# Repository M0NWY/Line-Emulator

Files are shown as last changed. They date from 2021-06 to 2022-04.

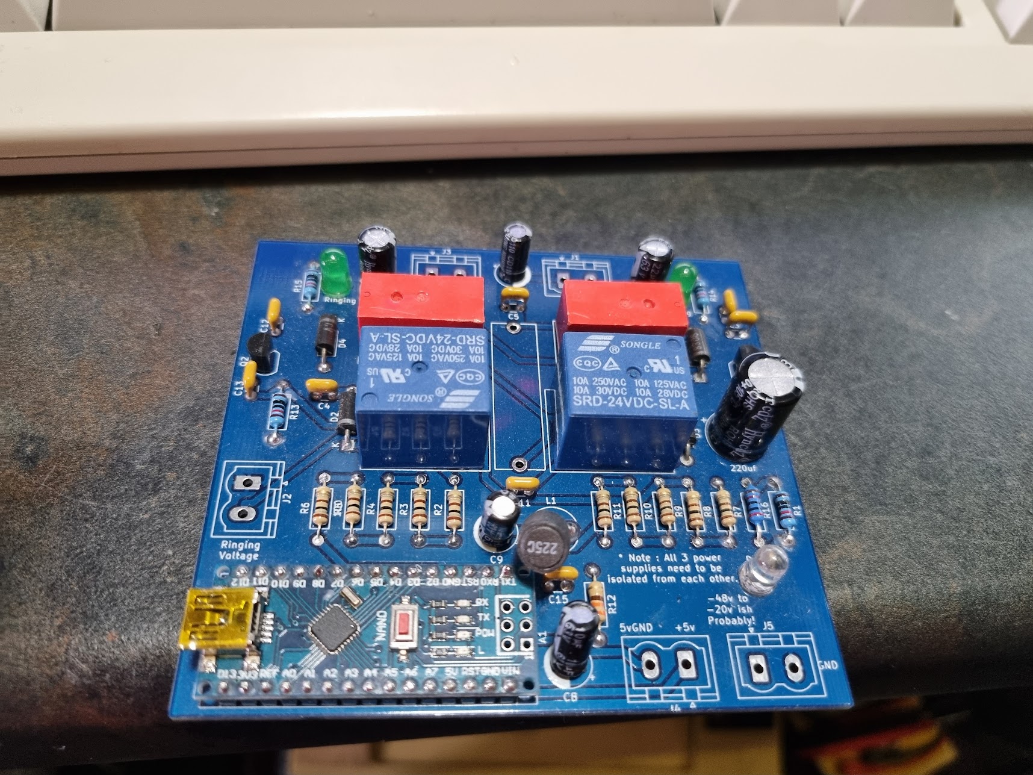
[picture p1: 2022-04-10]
lineemufront.jpg

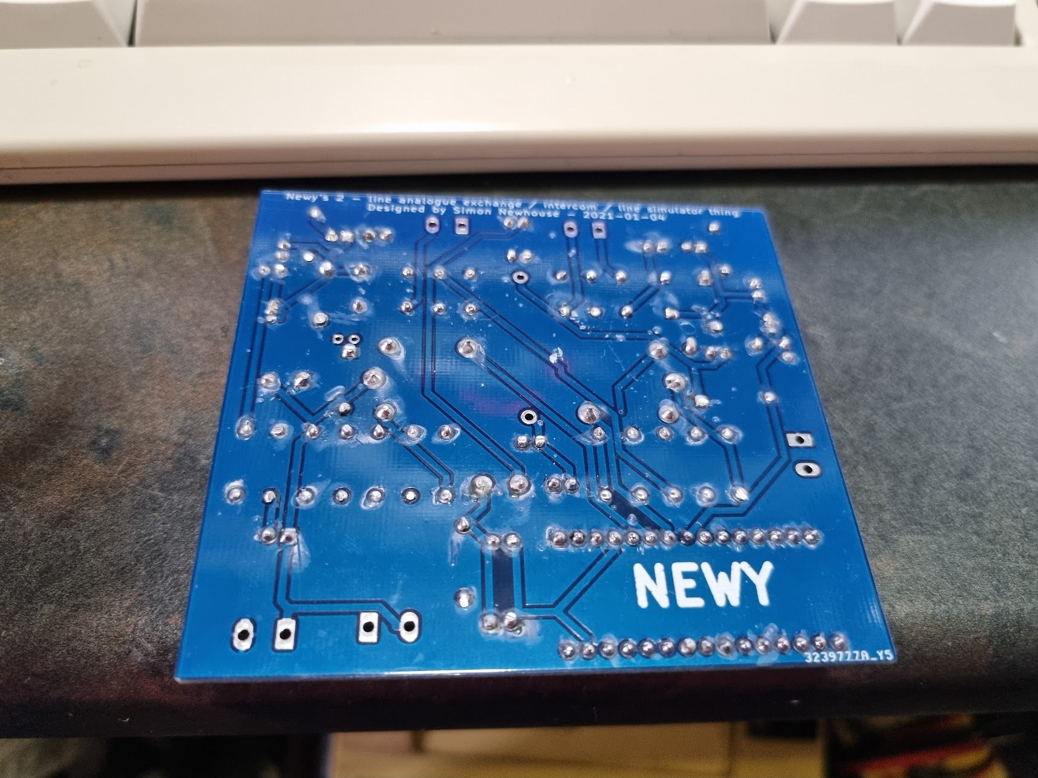
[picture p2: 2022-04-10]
lineemuback.jpg

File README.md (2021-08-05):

# Line-Emulator
I wanted a thing that would let me connect two modems together, so I could connect my dreamcast to the internet. 
In 2020.
This is the result. It is also a dedicated hotline / intercom thing. Will work with most old analogue phones.
Includes an emulated dial tone with a delay before ringing the other line, standard uk ringing cadence and a timeout if the other line does not answer.

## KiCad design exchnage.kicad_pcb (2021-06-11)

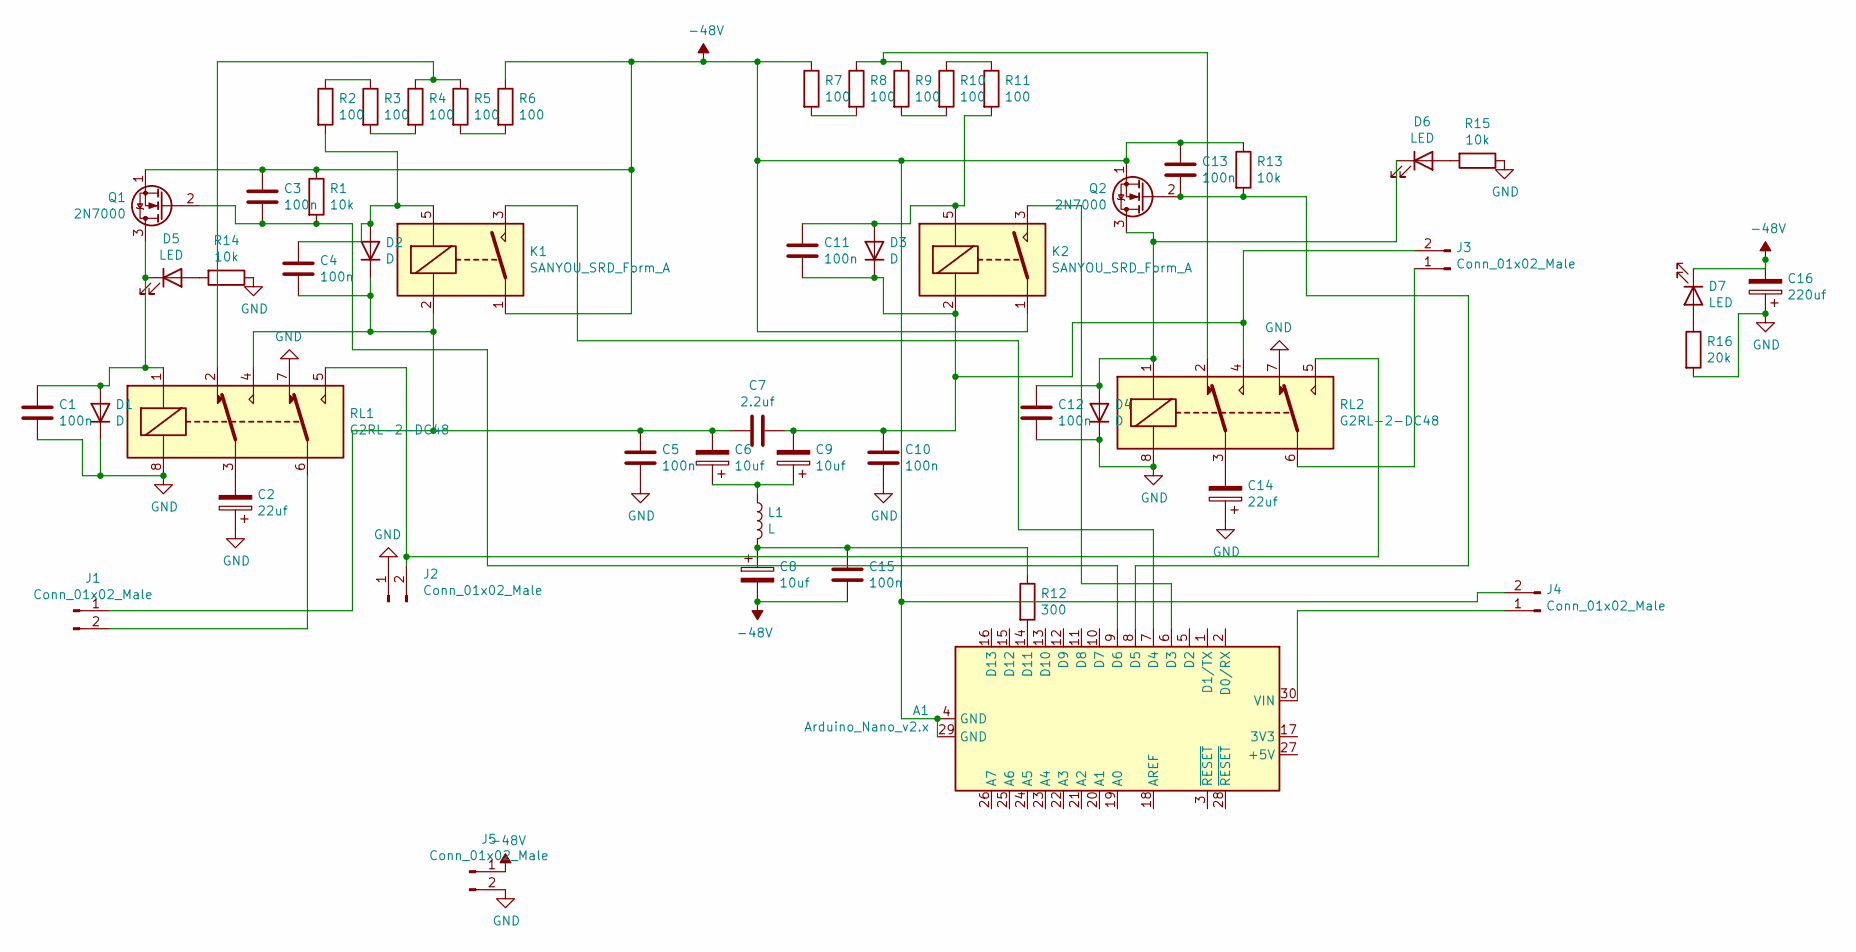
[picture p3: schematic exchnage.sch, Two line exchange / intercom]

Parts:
A1: Arduino_Nano_v2.x; Arduino_Nano
C1, C3, C4, C5, C10, C11, C12, C13, C15: 100n; C_Disc_D3.0mm_W1.6mm_P2.50mm
C2, C14: 22uf; CP_Radial_D6.3mm_P2.50mm
C6, C8, C9: 10uf; CP_Radial_D6.3mm_P2.50mm
C7: 2.2uf; C_Rect_L29.0mm_W7.6mm_P27.50mm_MKT
C16: 220uf; CP_Radial_D10.0mm_P5.00mm
D1, D2, D3, D4: D; D_A-405_P10.16mm_Horizontal
D5, D6, D7: LED; LED_D3.0mm
J1, J2, J3, J4, J5: Conn_01x02_Male; PhoenixContact_MSTBVA_2,5_2-G-5,08_1x02_P5.08mm_Vertical
K1, K2: SANYOU_SRD_Form_A; Relay_SPST_SANYOU_SRD_Series_Form_A
L1: L; L_Radial_D7.5mm_P5.00mm_Fastron_07P
Q1, Q2: 2N7000; TO-92_Inline
R1, R13, R14, R15: 10k; R_Axial_DIN0207_L6.3mm_D2.5mm_P10.16mm_Horizontal
R2, R3, R4, R5, R6, R7, R8, R9, R10, R11: 100; R_Axial_DIN0207_L6.3mm_D2.5mm_P10.16mm_Horizontal
R12: 300; R_Axial_DIN0207_L6.3mm_D2.5mm_P10.16mm_Horizontal
R16: 20k; R_Axial_DIN0207_L6.3mm_D2.5mm_P10.16mm_Horizontal
RL1, RL2: G2RL-2-DC48; Relay_DPDT_Omron_G2RL

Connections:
-48V: A1.4 (GND), A1.29 (GND), C3.1, C8.2, C13.1, C15.2, C16.2, D7.1 (K), J4.2, J5.1, K1.1, K2.1, Q1.1 (S), Q2.1 (S), R1.1, R6.1, R7.1, R13.1
GND: C1.2, C2.1, C5.2, C10.2, C12.2, C14.1, C16.1, D1.1 (K), D4.1 (K), J2.1, J5.2, R14.1, R15.1, R16.2, RL1.7, RL1.8, RL2.7, RL2.8
unnamed: A1.6 (D3), K2.3
unnamed: A1.7 (D4), K1.3
unnamed: A1.8 (D5), C13.2, Q2.2 (G), R13.2
unnamed: A1.9 (D6), C3.2, Q1.2 (G), R1.2
unnamed: A1.14 (D11), R12.2
unnamed: A1.30 (VIN), J4.1
unnamed: C1.1, D1.2 (A), D5.1 (K), Q1.3 (D), RL1.1
unnamed: C2.2, RL1.3
unnamed: C4.1, D2.2 (A), K1.5, R2.2
unnamed: C4.2, C5.1, C6.2, C7.2, D2.1 (K), J1.1, K1.2, RL1.4
unnamed: C6.1, C9.1, L1.1
unnamed: C7.1, C9.2, C10.1, C11.2, D3.1 (K), J3.2, K2.2, RL2.4
unnamed: C11.1, D3.2 (A), K2.5, R11.2
unnamed: C12.1, D4.2 (A), D6.1 (K), Q2.3 (D), RL2.1
unnamed: C14.2, RL2.3
unnamed: C8.1, C15.1, L1.2, R12.1
unnamed: D5.2 (A), R14.2
unnamed: D6.2 (A), R15.2
unnamed: D7.2 (A), R16.1
unnamed: J1.2, RL1.6
unnamed: J2.2, RL1.5, RL2.5
unnamed: J3.1, RL2.6
unnamed: R2.1, R3.1
unnamed: R3.2, R4.2
unnamed: R4.1, R5.1, RL1.2
unnamed: R5.2, R6.2
unnamed: R7.2, R8.2
unnamed: R8.1, R9.1, RL2.2
unnamed: R10.1, R11.1
unnamed: R9.2, R10.2

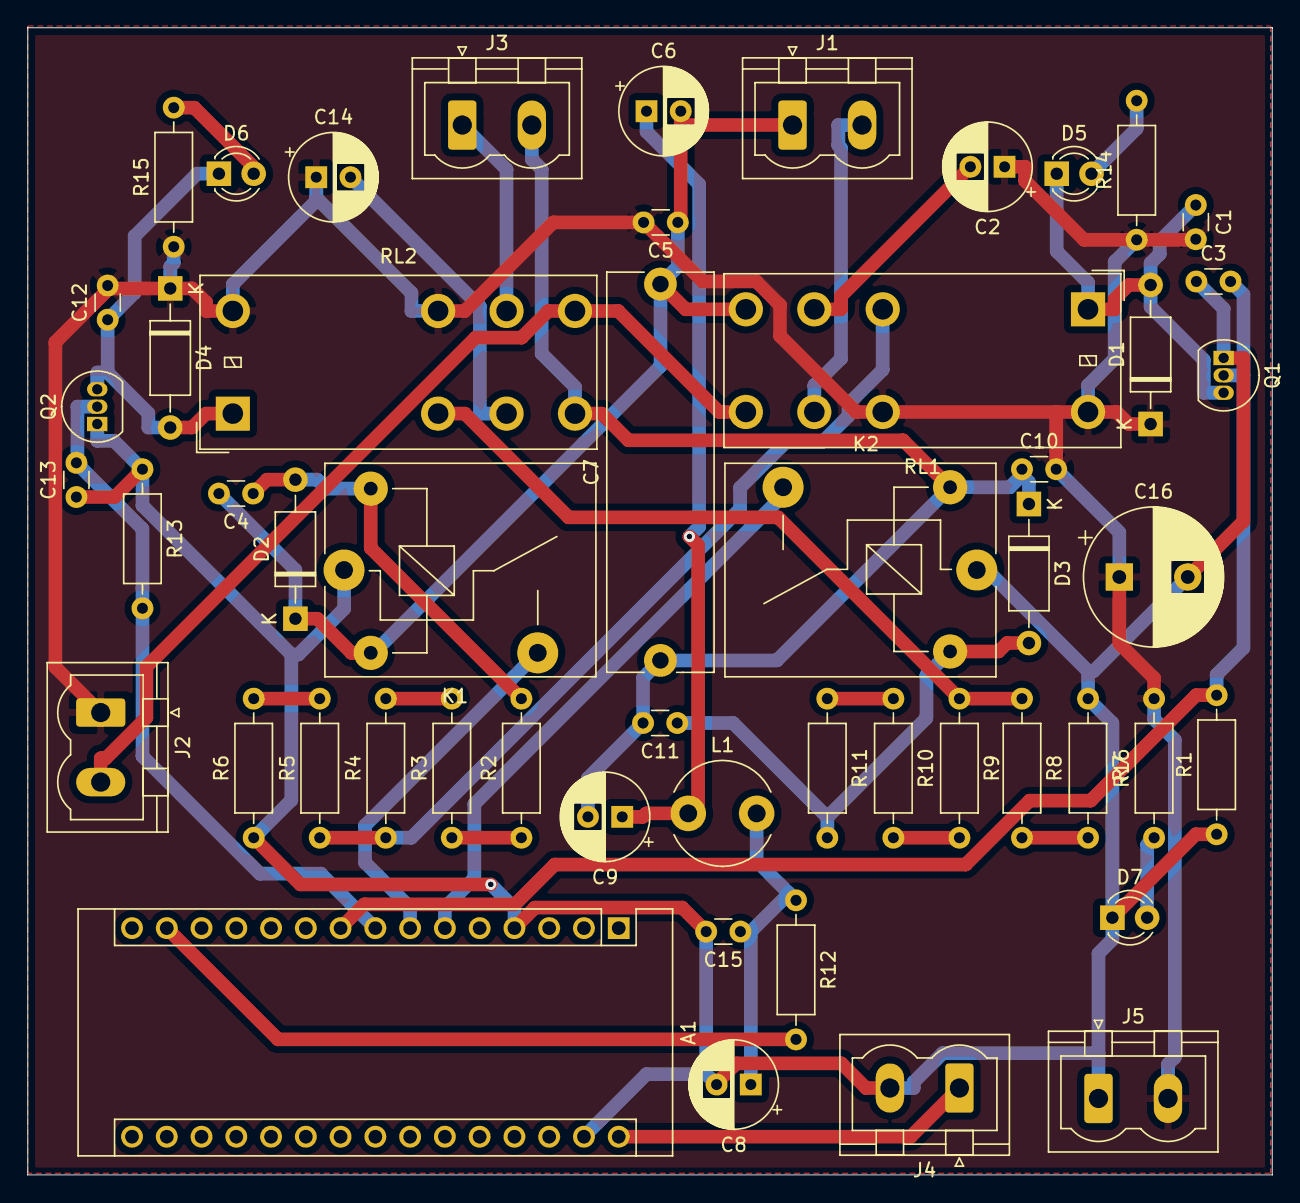
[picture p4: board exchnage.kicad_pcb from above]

Board: 2 copper layers, 90.9 x 83.8 mm, 52 parts (0 on the bottom side), 32 nets.

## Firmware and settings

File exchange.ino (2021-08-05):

//code for 2 line micro exchange
//only one call at a time - but sort of generalized.
//arduino c++ style. Not pyhton !
// vars and consts

int linepins[] = {3,4};
int ringpins[] = {5,6};
const int linecount = 2;
const int dialingdelay = 5000; // ms
const int debounce = 500; // ms
long unsigned int ringtimeout = 60000; // ms
const int dtpin = 11; // dialtone pin
//setup
void setup(){
pinMode(dtpin, OUTPUT);
for (int thisPin = 0; thisPin < linecount; thisPin++) {

    pinMode(linepins[thisPin], INPUT_PULLUP);
	  pinMode(ringpins[thisPin], OUTPUT);
    digitalWrite(ringpins[thisPin], LOW );
}
}
// Functions ?

void loop(){
// sits waiting for a line to go off hook

for (int line = 0; line < linecount; line++){ 
	bool state = ( digitalRead(linepins[line]) == LOW );
	if (state) { // a line has gone off hook !
    delay(debounce);
    if ( digitalRead(linepins[line]) == LOW ) {
      Dialtone(dialingdelay, line); 
      if ( digitalRead(linepins[line]) == LOW ) {
		// delay(dialingdelay);
		if (ring(!line) == 1 ) { waitforclear(line); }
		else {
			waitforcalltoend();
		}}
}}
}
}

//This is the standard BT ring
//Ring for 60 seconds, 400ms ring, 200ms pause, 400ms ring, 2000ms pause.

int ring(int ringline) {
bool bail = false ;
bool ringing = false;
bool f1;
bool f2;
long unsigned int t1 = millis();
long unsigned int t2 = micros();
long unsigned int t3 = t2 ;
long unsigned int t4 = t1 ;
while (!bail) {

long unsigned int mafs = millis() - t1 ;
long unsigned int mafs2 = micros() - t2 ;
long unsigned int mafs3 = micros() - t3 ;
long unsigned int mafs4 = millis() - t4 ;

if ((mafs < 400) || (mafs > 600 && mafs < 1000)) {
digitalWrite(ringpins[ringline], HIGH) ;
ringing = true;
}
else { 
digitalWrite(ringpins[ringline], LOW) ;
ringing = false;
}
if ( mafs > 3000 ) { t1 = millis(); }
if ( mafs4 > ringtimeout ) { 
  digitalWrite(ringpins[ringline], LOW );
  digitalWrite(dtpin, LOW);
  return 1; // timeout
bail = true ; // will never execute ? 
 }
if ( digitalRead(linepins[!ringline]) == HIGH ) { // clalling line hung up before timeout
  delay(debounce);
  if ( digitalRead(linepins[!ringline]) == HIGH ) {
    
    digitalWrite(ringpins[ringline], LOW );
    digitalWrite(dtpin, LOW);
    return 0;
  }
  }

if ( digitalRead(linepins[ringline]) == LOW ) { // call answerered
  delay(debounce);
  if ( digitalRead(linepins[ringline]) == LOW ) {
    digitalWrite(ringpins[ringline], LOW );
    digitalWrite(dtpin, LOW);
return 2 ; 
bail = true ;// will never execute ? 
}
}
if (ringing) { // code for audio ringing tone 
  // 400hz period 1/400 = 0.0025
  // 450hz period 1/450 = 0.002222222 etc..
  if ( mafs2 < 1250 ) {f1 = true; }
  else { f1 = false; }
  if ( mafs2 > 2500 ) { t2 = micros(); }
  if ( mafs3 < 1111 ) { f2 = true ; }
  else { f2 = false; }
  if ( mafs3 > 2222 ) { t3 = micros(); }
  if ( f1 | f2 ) { digitalWrite(dtpin, HIGH); } // & and | seem to work ok. Dunno why ! mafs.. innit!
  else { digitalWrite(dtpin, LOW); }
  }
}
}

void waitforclear(int rungline) {
  long unsigned int mictime400 = micros();
	while (true) {
    long unsigned int tot = micros() - mictime400 ; //400hz period = 1/400 = 0.0025
    if ( tot < 1250 ) { digitalWrite(dtpin, HIGH); }
    else { digitalWrite(dtpin, LOW); }
    if ( tot > 2500 ) { mictime400 = micros(); }
    
		if (digitalRead(linepins[rungline])==HIGH) { 
      digitalWrite(dtpin, LOW);
		  return; }
	}
}
	
void waitforcalltoend() {
	// count all lines off hook bail if == 0
	while (true) {
int	acc = 0;
		for (int line = 0; line < linecount; line++){ 
			acc = acc + (digitalRead(linepins[line])== HIGH) ; 
		}
		if ( acc == linecount ) { return; } // lines are high when on hook
	}
}

void Dialtone(int tonetime, int line) {
  long unsigned int miltime = millis();
  long unsigned int mictime450 = micros();
  long unsigned int mictime350 = mictime450;
  bool flag450;
  bool flag350;
  
  //450hz period = 1/450 = 0.002222222222222222 ish
  //350hz period = 1/350 = 0.00285714285 ish
  //for 50% duty on for half period off for half.
  
  while (true) {
    // did we hangup before we connected started ringing  ?

    
    if ( digitalRead(linepins[line]) == HIGH ) {
      delay(debounce);
      if ( digitalRead(linepins[line]) == HIGH ) {
        return ;
      }
    }
    long unsigned int dif450 = micros() - mictime450 ;
    long unsigned int dif350 = micros() - mictime350 ;
    if (dif450 < 1111) {
      flag450 = true;
    }
    else
    { flag450 = false; }
    if (dif450 > 2222) { mictime450 = micros(); }

    if (dif350 < 1428) {
      flag350 = true;
    }
    else {
      flag350 = false;
    }
    if (dif350 > 2857) { mictime350 = micros(); }
    if ((millis() - miltime) > tonetime ) { return; }

    if ( flag450 | flag350 ) {
      digitalWrite(dtpin, HIGH);
    }
    else
    {
      digitalWrite(dtpin, LOW);
    }
  }}
    
